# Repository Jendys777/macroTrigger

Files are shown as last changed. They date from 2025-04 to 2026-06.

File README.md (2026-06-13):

This is opensource project of a macro keyboard or pad. I call it macroTrigger. As it triggers some macros on your computer.

If you have any questions please read the manual first. Than send me a messagge with question. if you have one.

You can also find the 3D models here: https://www.printables.com/model/1269446-macrotrigger

UPDATE NOTES: 
- V3 firmware helps with the flashing process. Previously, you had to manually reset the device by shorting the RST and GND pins. Now, simply unplug the device, press and hold the encoder, and plug it back in. Keep holding the encoder while starting the flash in your IDE. Once the upload is finished, release the encoder, replug the device, and you are ready to go.

Please DO NOT SHARE, OR SELL THIS PRODCT, without my perrmision. 

contact me on: info@bojler.org

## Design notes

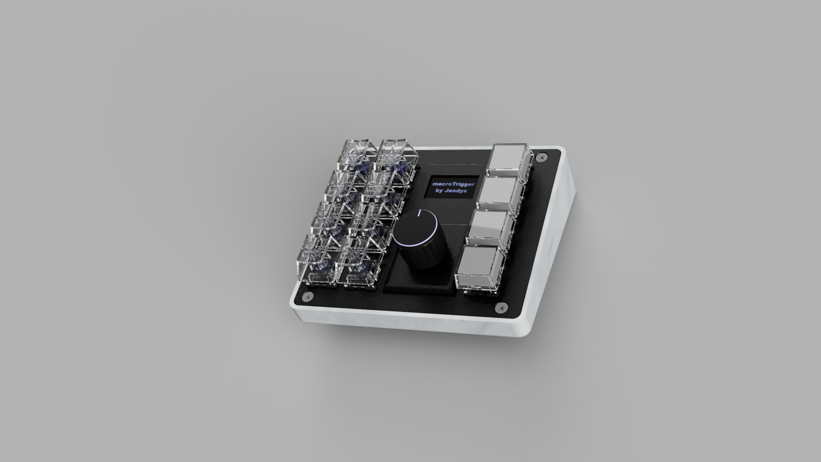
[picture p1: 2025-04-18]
Render1.PNG

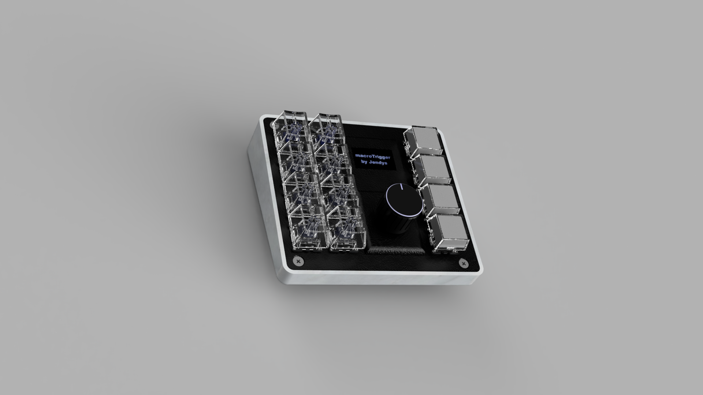
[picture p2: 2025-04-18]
Render2.PNG

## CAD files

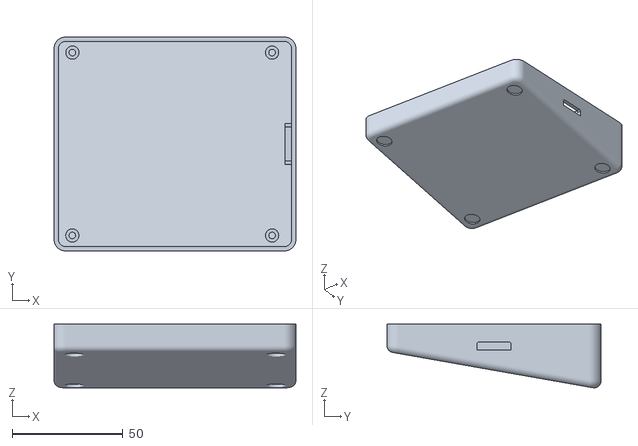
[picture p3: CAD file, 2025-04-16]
3DMODELS/macroTriggerBOTTOMCOVER.stl
109.2 x 96.6 x 28.8

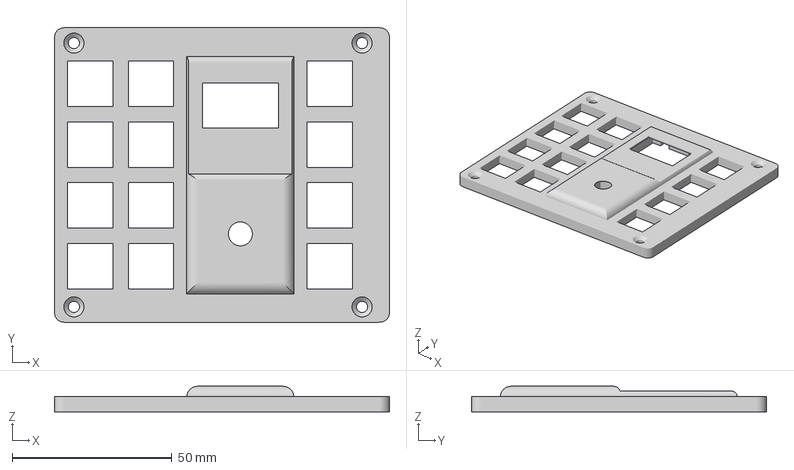
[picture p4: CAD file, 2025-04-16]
3DMODELS/macroTriggerTOPCOVER.3mf
104.8 x 92.2 x 8.00 mm

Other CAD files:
3DMODELS/macroTriggerTOPCOVER.stl

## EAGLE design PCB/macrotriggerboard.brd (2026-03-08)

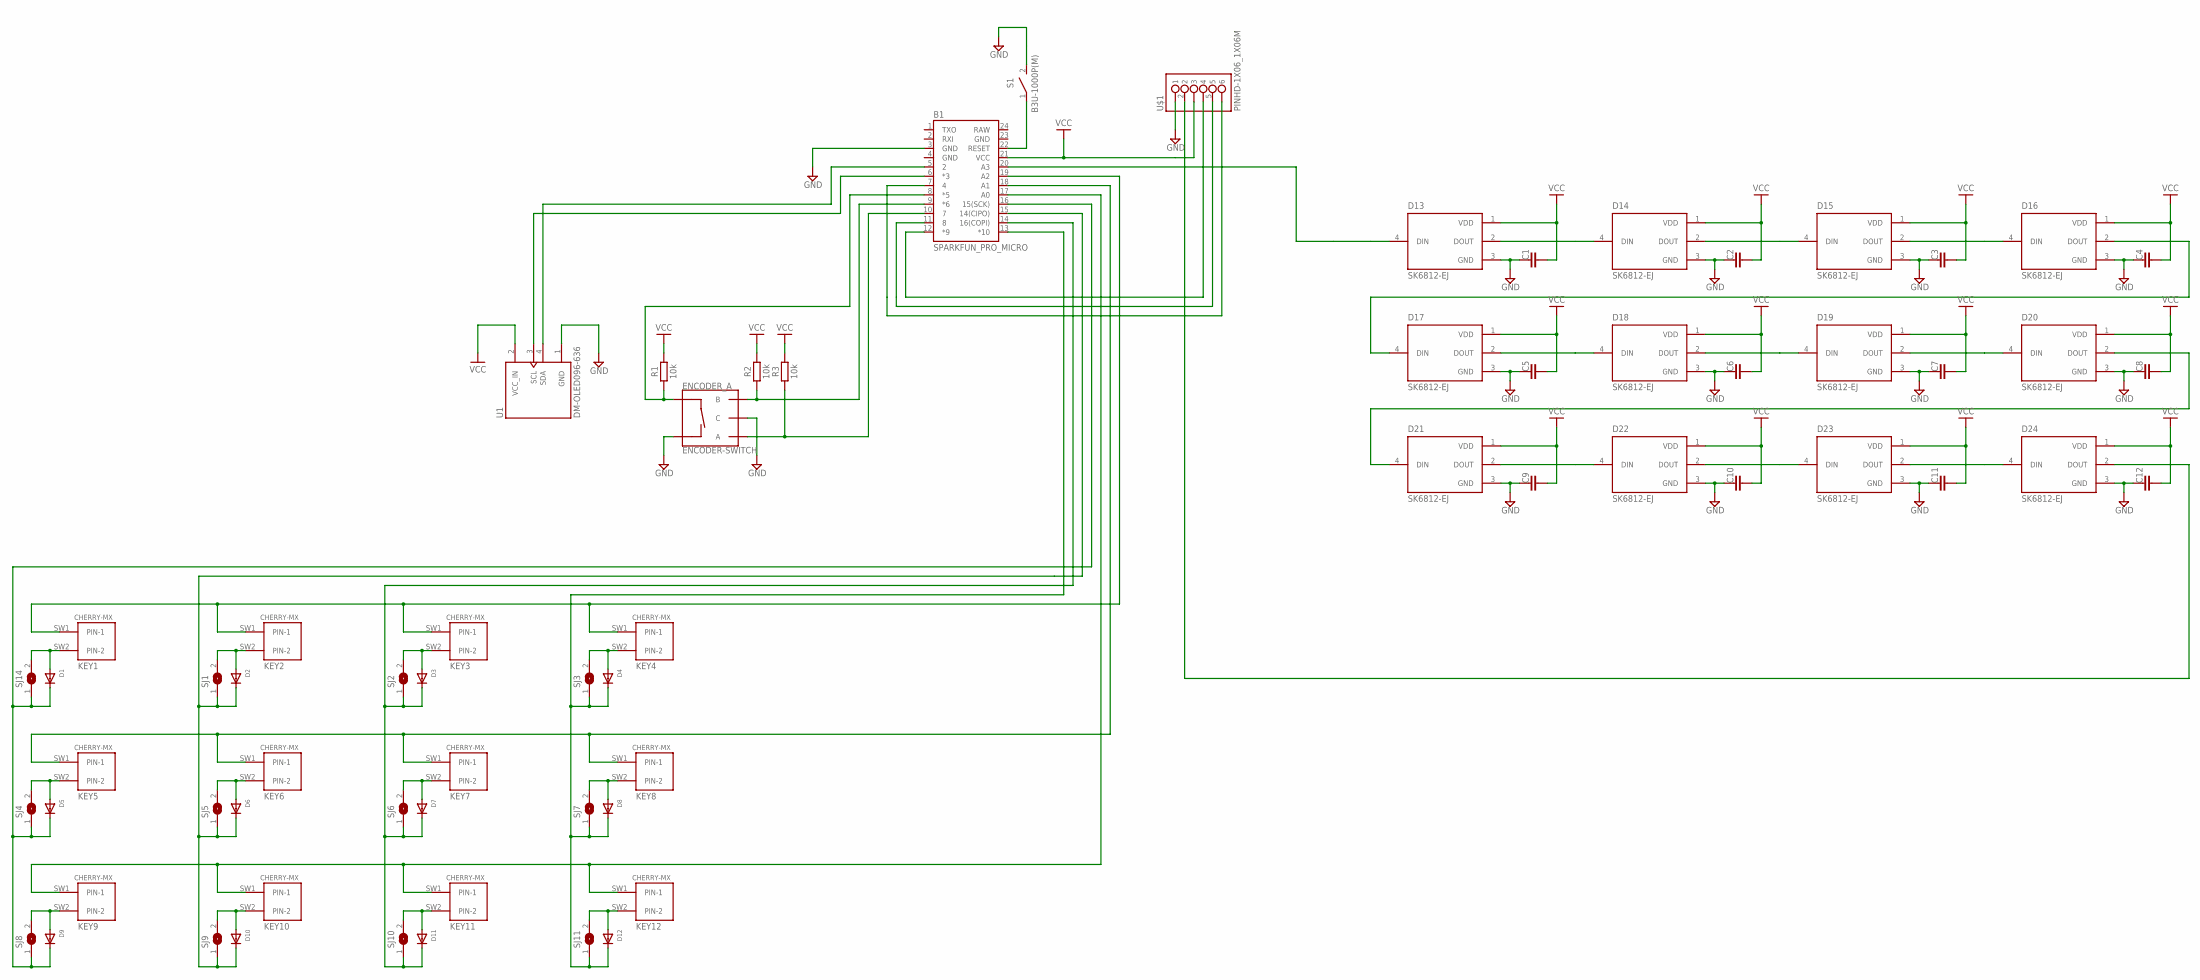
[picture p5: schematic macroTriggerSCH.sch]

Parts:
B1: SPARKFUN_PRO_MICRO
C1, C2, C3, C4, C5, C6, C7, C8, C9, C10, C11, C12: C_CHIP-0805(2012-METRIC); CAPC2012X110
D1, D2, D3, D4, D5, D6, D7, D8, D9, D10, D11, D12: DIODESOD-123; SOD-123
D13, D14, D15, D16, D17, D18, D19, D20, D21, D22, D23, D24: SK6812-EJ; LED_SK6812-E
ENCODER_A: ENCODER-SWITCH; ROTARY_ENC_PLAIN
KEY1, KEY2, KEY3, KEY4, KEY5, KEY6, KEY7, KEY8, KEY9, KEY10, KEY11, KEY12: CHERRY-MX
R1, R2, R3: 10k; RESC3216X70
S1: B3U-1000P(M)
SJ1, SJ2, SJ3, SJ4, SJ5, SJ6, SJ7, SJ8, SJ9, SJ10, SJ11, SJ14: SJ
U1: DM-OLED096-636; MODULE_DM-OLED096-636
U$1: PINHD-1X06_1X06M; 1X06

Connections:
GND: B1.3 (GND), B1.4 (GND), B1.23 (GND), C1.1, C2.1, C3.1, C4.1, C5.1, C6.1, C7.1, C8.1, C9.1, C10.1, C11.1, C12.1, D13.3 (GND), D14.3 (GND), D15.3 (GND), D16.3 (GND), D17.3 (GND), D18.3 (GND), D19.3 (GND), D20.3 (GND), D21.3 (GND), D22.3 (GND), D23.3 (GND), D24.3 (GND), ENCODER_A.C, ENCODER_A.SW-, S1.2, U1.1 (GND), U$1.1
unnamed: B1.22 (RESET), S1.1
unnamed: D1.A, KEY1.SW2 (PIN-2), SJ14.2
unnamed: D2.A, KEY2.SW2 (PIN-2), SJ1.2
unnamed: B1.15 (14(CIPO)), D2.C, D6.C, D10.C, SJ1.1, SJ5.1, SJ9.1
unnamed: D24.2 (DOUT), U$1.2
unnamed: B1.10 (7), ENCODER_A.A, R3.1
unnamed: D3.A, KEY3.SW2 (PIN-2), SJ2.2
unnamed: B1.19 (A2), KEY1.SW1 (PIN-1), KEY2.SW1 (PIN-1), KEY3.SW1 (PIN-1), KEY4.SW1 (PIN-1)
unnamed: D13.2 (DOUT), D14.4 (DIN)
unnamed: D4.A, KEY4.SW2 (PIN-2), SJ3.2
unnamed: B1.20 (A3), D13.4 (DIN)
unnamed: D5.A, KEY5.SW2 (PIN-2), SJ4.2
unnamed: D6.A, KEY6.SW2 (PIN-2), SJ5.2
unnamed: B1.13 (*10), D4.C, D8.C, D12.C, SJ3.1, SJ7.1, SJ11.1
unnamed: D7.A, KEY7.SW2 (PIN-2), SJ6.2
unnamed: D8.A, KEY8.SW2 (PIN-2), SJ7.2
unnamed: D9.A, KEY9.SW2 (PIN-2), SJ8.2
unnamed: D10.A, KEY10.SW2 (PIN-2), SJ9.2
unnamed: B1.14 (16(COPI)), D3.C, D7.C, D11.C, SJ2.1, SJ6.1, SJ10.1
unnamed: D11.A, KEY11.SW2 (PIN-2), SJ10.2
unnamed: D12.A, KEY12.SW2 (PIN-2), SJ11.2
unnamed: B1.11 (8), U$1.5
unnamed: B1.12 (*9), U$1.4
unnamed: B1.7 (4), U$1.6
unnamed: D14.2 (DOUT), D15.4 (DIN)
unnamed: D15.2 (DOUT), D16.4 (DIN)
unnamed: B1.18 (A1), KEY5.SW1 (PIN-1), KEY6.SW1 (PIN-1), KEY7.SW1 (PIN-1), KEY8.SW1 (PIN-1)
unnamed: B1.9 (*6), ENCODER_A.B, R2.1
unnamed: B1.8 (*5), ENCODER_A.SW+, R1.1
unnamed: B1.5 (2), U1.4 (SDA)
unnamed: B1.6 (*3), U1.3 (SCL)
unnamed: B1.17 (A0), KEY9.SW1 (PIN-1), KEY10.SW1 (PIN-1), KEY11.SW1 (PIN-1), KEY12.SW1 (PIN-1)
unnamed: D16.2 (DOUT), D17.4 (DIN)
unnamed: B1.16 (15(SCK)), D1.C, D5.C, D9.C, SJ4.1, SJ8.1, SJ14.1
unnamed: D17.2 (DOUT), D18.4 (DIN)
unnamed: D18.2 (DOUT), D19.4 (DIN)
unnamed: D19.2 (DOUT), D20.4 (DIN)
unnamed: D20.2 (DOUT), D21.4 (DIN)
unnamed: D21.2 (DOUT), D22.4 (DIN)
unnamed: D22.2 (DOUT), D23.4 (DIN)
unnamed: D23.2 (DOUT), D24.4 (DIN)
RAW: B1.24 (RAW)
VCC: B1.21 (VCC), C1.2, C2.2, C3.2, C4.2, C5.2, C6.2, C7.2, C8.2, C9.2, C10.2, C11.2, C12.2, D13.1 (VDD), D14.1 (VDD), D15.1 (VDD), D16.1 (VDD), D17.1 (VDD), D18.1 (VDD), D19.1 (VDD), D20.1 (VDD), D21.1 (VDD), D22.1 (VDD), D23.1 (VDD), D24.1 (VDD), R1.2, R2.2, R3.2, U1.2 (VCC_IN), U$1.3


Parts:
B1: SPARKFUN_PRO_MICRO
C1, C2, C3, C4, C5, C6, C7, C8, C9, C10, C11, C12: C_CHIP-0805(2012-METRIC); CAPC2012X110
D1, D2, D3, D4, D5, D6, D7, D8, D9, D10, D11, D12: DIODESOD-123; SOD-123
D13, D14, D15, D16, D17, D18, D19, D20, D21, D22, D23, D24: SK6812-EJ; LED_SK6812-E
ENCODER_A: ENCODER-SWITCH; ROTARY_ENC_PLAIN
KEY1, KEY2, KEY3, KEY4, KEY5, KEY6, KEY7, KEY8, KEY9, KEY10, KEY11, KEY12: CHERRY-MX
R1, R2, R3: 10k; RESC3216X70
S1: B3U-1000P(M)
SJ1, SJ2, SJ3, SJ4, SJ5, SJ6, SJ7, SJ8, SJ9, SJ10, SJ11, SJ14: SJ
U1: DM-OLED096-636; MODULE_DM-OLED096-636
U$1: PINHD-1X06_1X06M; 1X06

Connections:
GND: B1.3 (GND), B1.4 (GND), B1.23 (GND), C1.1, C2.1, C3.1, C4.1, C5.1, C6.1, C7.1, C8.1, C9.1, C10.1, C11.1, C12.1, D13.3 (GND), D14.3 (GND), D15.3 (GND), D16.3 (GND), D17.3 (GND), D18.3 (GND), D19.3 (GND), D20.3 (GND), D21.3 (GND), D22.3 (GND), D23.3 (GND), D24.3 (GND), ENCODER_A.C, ENCODER_A.SW-, S1.2, U1.1 (GND), U$1.1
unnamed: B1.22 (RESET), S1.1
unnamed: D1.A, KEY1.SW2 (PIN-2), SJ14.2
unnamed: D2.A, KEY2.SW2 (PIN-2), SJ1.2
unnamed: B1.15 (14(CIPO)), D2.C, D6.C, D10.C, SJ1.1, SJ5.1, SJ9.1
unnamed: D24.2 (DOUT), U$1.2
unnamed: B1.10 (7), ENCODER_A.A, R3.1
unnamed: D3.A, KEY3.SW2 (PIN-2), SJ2.2
unnamed: B1.19 (A2), KEY1.SW1 (PIN-1), KEY2.SW1 (PIN-1), KEY3.SW1 (PIN-1), KEY4.SW1 (PIN-1)
unnamed: D13.2 (DOUT), D14.4 (DIN)
unnamed: D4.A, KEY4.SW2 (PIN-2), SJ3.2
unnamed: B1.20 (A3), D13.4 (DIN)
unnamed: D5.A, KEY5.SW2 (PIN-2), SJ4.2
unnamed: D6.A, KEY6.SW2 (PIN-2), SJ5.2
unnamed: B1.13 (*10), D4.C, D8.C, D12.C, SJ3.1, SJ7.1, SJ11.1
unnamed: D7.A, KEY7.SW2 (PIN-2), SJ6.2
unnamed: D8.A, KEY8.SW2 (PIN-2), SJ7.2
unnamed: D9.A, KEY9.SW2 (PIN-2), SJ8.2
unnamed: D10.A, KEY10.SW2 (PIN-2), SJ9.2
unnamed: B1.14 (16(COPI)), D3.C, D7.C, D11.C, SJ2.1, SJ6.1, SJ10.1
unnamed: D11.A, KEY11.SW2 (PIN-2), SJ10.2
unnamed: D12.A, KEY12.SW2 (PIN-2), SJ11.2
unnamed: B1.11 (8), U$1.5
unnamed: B1.12 (*9), U$1.4
unnamed: B1.7 (4), U$1.6
unnamed: D14.2 (DOUT), D15.4 (DIN)
unnamed: D15.2 (DOUT), D16.4 (DIN)
unnamed: B1.18 (A1), KEY5.SW1 (PIN-1), KEY6.SW1 (PIN-1), KEY7.SW1 (PIN-1), KEY8.SW1 (PIN-1)
unnamed: B1.9 (*6), ENCODER_A.B, R2.1
unnamed: B1.8 (*5), ENCODER_A.SW+, R1.1
unnamed: B1.5 (2), U1.4 (SDA)
unnamed: B1.6 (*3), U1.3 (SCL)
unnamed: B1.17 (A0), KEY9.SW1 (PIN-1), KEY10.SW1 (PIN-1), KEY11.SW1 (PIN-1), KEY12.SW1 (PIN-1)
unnamed: D16.2 (DOUT), D17.4 (DIN)
unnamed: B1.16 (15(SCK)), D1.C, D5.C, D9.C, SJ4.1, SJ8.1, SJ14.1
unnamed: D17.2 (DOUT), D18.4 (DIN)
unnamed: D18.2 (DOUT), D19.4 (DIN)
unnamed: D19.2 (DOUT), D20.4 (DIN)
unnamed: D20.2 (DOUT), D21.4 (DIN)
unnamed: D21.2 (DOUT), D22.4 (DIN)
unnamed: D22.2 (DOUT), D23.4 (DIN)
unnamed: D23.2 (DOUT), D24.4 (DIN)
RAW: B1.24 (RAW)
VCC: B1.21 (VCC), C1.2, C2.2, C3.2, C4.2, C5.2, C6.2, C7.2, C8.2, C9.2, C10.2, C11.2, C12.2, D13.1 (VDD), D14.1 (VDD), D15.1 (VDD), D16.1 (VDD), D17.1 (VDD), D18.1 (VDD), D19.1 (VDD), D20.1 (VDD), D21.1 (VDD), D22.1 (VDD), D23.1 (VDD), D24.1 (VDD), R1.2, R2.2, R3.2, U1.2 (VCC_IN), U$1.3

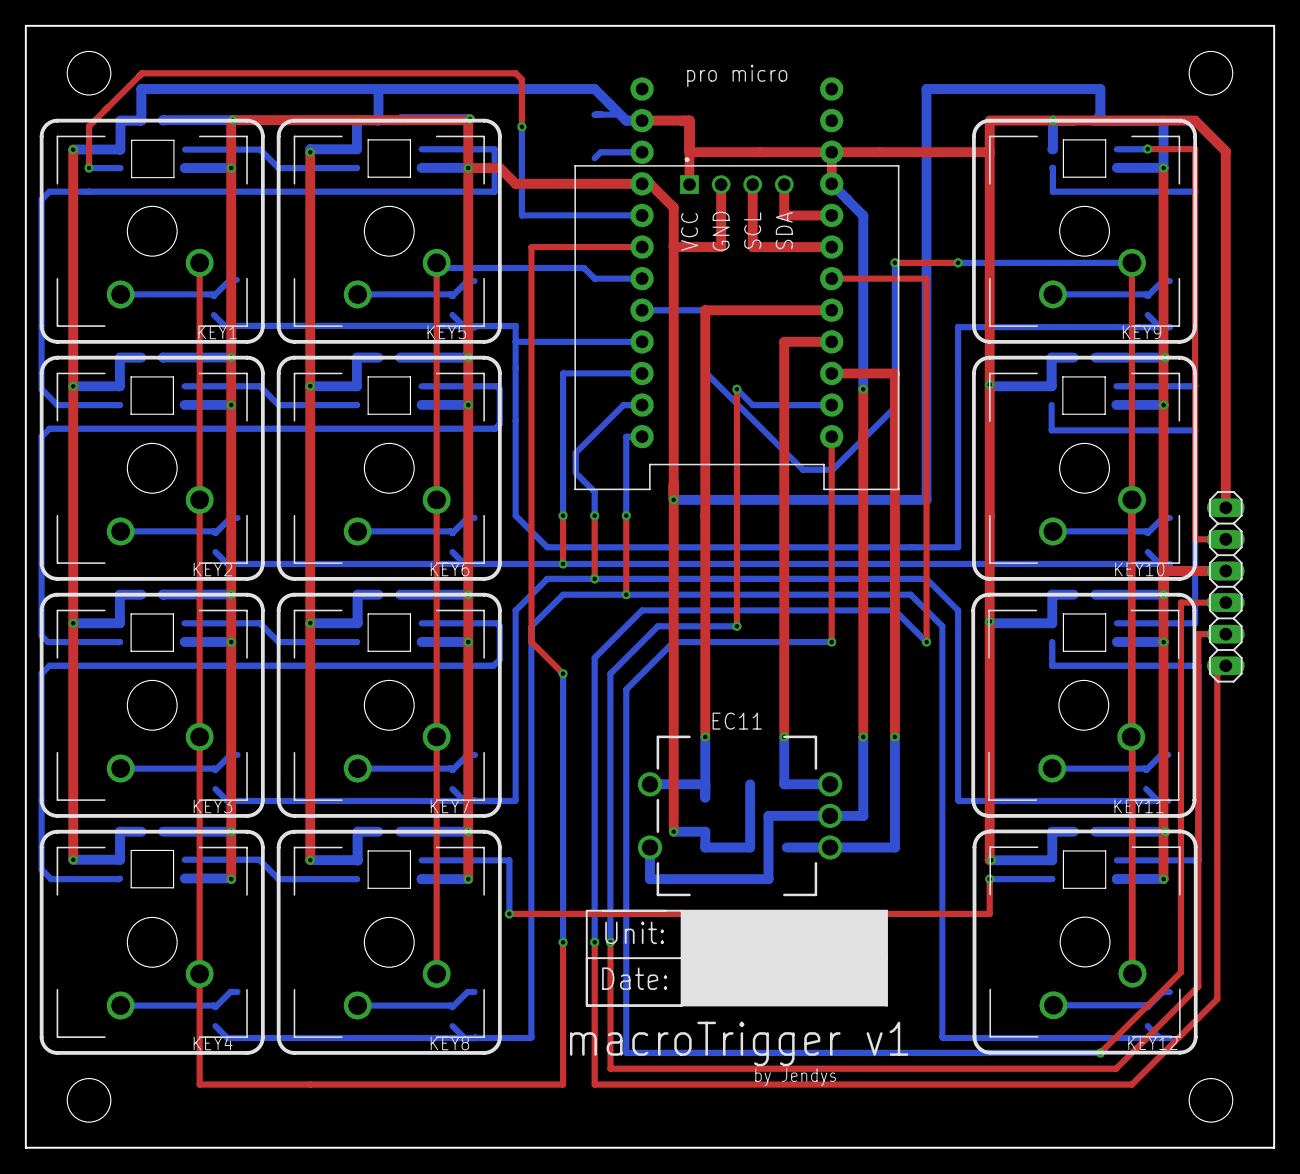
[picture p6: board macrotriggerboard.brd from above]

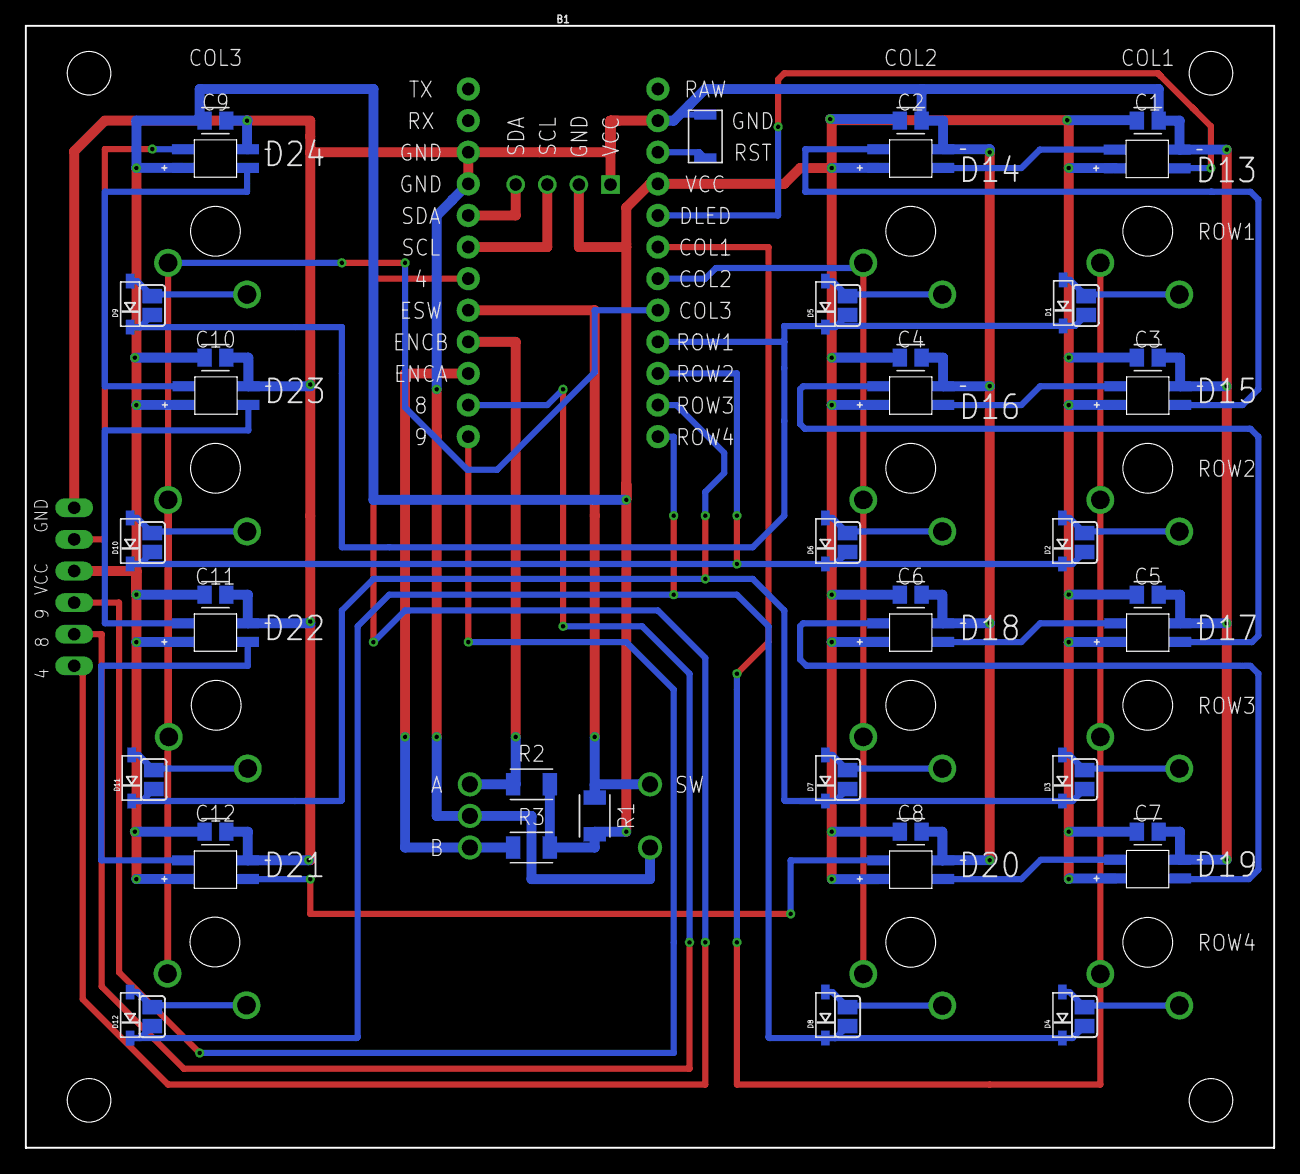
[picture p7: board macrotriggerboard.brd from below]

Board: 2 copper layers, 100.3 x 90.2 mm, 68 parts (53 on the bottom side), 43 nets.

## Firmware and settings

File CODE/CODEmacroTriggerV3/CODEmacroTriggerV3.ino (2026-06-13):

//Libraries
#include <Adafruit_NeoPixel.h>
#include <Keypad.h>
#include <Encoder.h>
#include <Wire.h>
#include <Adafruit_GFX.h>
#include <Adafruit_SSD1306.h>
#include <HID-Project.h>
#include <HID-Settings.h>
#include <EEPROM.h>

//NeoPixel Setup
#define LED_PIN A3
#define LED_COUNT 13 
Adafruit_NeoPixel strip(LED_COUNT, LED_PIN, NEO_GRB + NEO_KHZ800);

//OLED Display Setup
#define SCREEN_WIDTH 128
#define SCREEN_HEIGHT 64
#define OLED_RESET -1
Adafruit_SSD1306 display(SCREEN_WIDTH, SCREEN_HEIGHT, &Wire, OLED_RESET);

//Keypad Setup
const byte ROWS = 4;
const byte COLS = 3;
char hexaKeys[ROWS][COLS] = {
  { '1', '2', 'A' },
  { '3', '4', 'B' },
  { '5', '6', 'C' },
  { '7', '8', 'D' }
};
byte rowPins[ROWS] = { 15, 14, 16, 10 };
byte colPins[COLS] = { A2, A1, A0 };
Keypad customKeypad = Keypad(makeKeymap(hexaKeys), rowPins, colPins, ROWS, COLS);

//Encoder Setup
#define ENCODER_CLK 7
#define ENCODER_DT 6
#define ENCODER_SW 5
Encoder myEnc(ENCODER_CLK, ENCODER_DT);
long lastPosition = 0;
bool lastButtonState = HIGH;

//Timers
unsigned long lastKeyCheck = 0;
const unsigned long keyCheckInterval = 50;
unsigned long lastBPressTime = 0;
int bPressCount = 0;
const unsigned long doublePressInterval = 500;

// Button B Toggle Logic
bool bToggleState = false;  
const int BUTTON_B_LED = 10;

unsigned long lastMPressTime = 0;
int mPressCount = 0;

unsigned long lastLEDUpdateTime[3] = { 0, 0, 0 };
const unsigned long LEDUpdateInterval = 100;

//Saved variables
unsigned long mode = 1;
int ledA = 5;
int menu = 0;
int LED = 2;
bool mute = false;
bool enableL = false;
bool enable = true;
bool Light = true;
String function = "";
int bright = 100;

char preset1 = '1'; String pre1 = "Mode 1";
char preset2 = '2'; String pre2 = "Mode 2";
char preset3 = '3'; String pre3 = "Mode 3";
char preset4 = 'W'; String pre4 = "Windows M"; 

unsigned long currentMillis = millis();

void setup() {
  // --- NOUZOVÝ REŽIM PRO NAHRÁVÁNÍ KÓDU ---
  // Pokud držíš zmáčknuté tlačítko enkodéru při zapojení do USB,
  // macropad svítí oranžově a zastaví se, aby šlo normálně nahrávat.
  pinMode(ENCODER_SW, INPUT_PULLUP);
  if (digitalRead(ENCODER_SW) == LOW) {
    strip.begin();
    strip.setBrightness(50);
    for (int i = 0; i < LED_COUNT; i++) {
      strip.setPixelColor(i, strip.Color(255, 100, 0)); // Oranžová
    }
    strip.show();
    while (true) {
      // Nekonečná smyčka - procesor drží prázdnou USB linku připravenou pro flash.
    }
  }
  // --- KONEC NOUZOVÉHO REŽIMU ---

  Serial.begin(9600);
  strip.begin();
  EEPROM.get(10, bright);
  strip.setBrightness(bright);
  strip.show();
  display.begin(SSD1306_SWITCHCAPVCC, 0x3C);
  BootKeyboard.begin();
  Consumer.begin();

  //Startup animation Display
  display.clearDisplay();
  display.setTextColor(1);
  display.setTextSize(2);
  display.setCursor(35, 8);
  display.print("macro");
  display.setCursor(23, 28);
  display.print("Trigger");
  display.setTextSize(1);
  display.setCursor(16, 54);
  display.print("By: Jendys & KNC");
  display.display();

  //LEDs Startup
  for (int i = 0; i < LED_COUNT; i++) {
    strip.setPixelColor(i, strip.Color(255, 0, 0));
    strip.show();
    delay(100); 
  }
  EEPROM.get(0, mode);
  EEPROM.get(5, LED);
}

void loop() {
  currentMillis = millis();

  //Check keypad at interval
  if (currentMillis - lastKeyCheck >= keyCheckInterval) {
    lastKeyCheck = currentMillis;
    char key = customKeypad.getKey();
    if (key) {
      keyPress(key);
    }
  }

  // Handle Encoder Rotation
  long newPosition = myEnc.read() / 4;
  long encDiff = newPosition - lastPosition;

  switch (menu) {
    case 0: {
      // Volume Control
      if (encDiff > 0) Consumer.write(MEDIA_VOLUME_UP);
      else if (encDiff < 0) Consumer.write(MEDIA_VOLUME_DOWN);

      // Play / Pause
      bool buttonState = digitalRead(ENCODER_SW);
      if (buttonState == LOW && lastButtonState == HIGH) {
        Consumer.write(MEDIA_PLAY_PAUSE);
        delay(200);
      }
      lastButtonState = buttonState;

      enable = false;
      enableL = false;

      if (currentMillis - lastLEDUpdateTime[0] >= LEDUpdateInterval) {
        lastLEDUpdateTime[0] = currentMillis;
        setColor(LED);
        display.clearDisplay();
        display.setTextColor(1);
        display.setTextSize(1);
        display.setTextWrap(false);
        display.setCursor(6, 17);
        display.print(function);
        setDisplay(mode);
      }
      break;
    }
    case 1: {
      // Mode Selection
      if (encDiff > 0) mode = min(mode + 1, 4UL);
      else if (encDiff < 0) mode = max(mode - 1, 1UL);

      if (encDiff != 0) EEPROM.put(0, mode);

      enable = true;
      enableL = false;

      if (currentMillis - lastLEDUpdateTime[1] >= LEDUpdateInterval) {
        lastLEDUpdateTime[1] = currentMillis;
        setColor(LED);
        display.clearDisplay();
        display.setTextSize(1);
        display.setTextWrap(false);
        display.setCursor(33, 2);
        display.print("Select MODE");
        setDisplay(mode);
      }
      break;
    }
    case 2: {
      // Brightness Control
      if (encDiff > 0) bright = min(bright + 10, 250);
      else if (encDiff < 0) bright = max(bright - 10, 0);
      if (encDiff != 0) {
        strip.setBrightness(bright);
        EEPROM.put(10, bright);
      }

      enable = false;
      enableL = true;

      if (currentMillis - lastLEDUpdateTime[2] >= LEDUpdateInterval) {
        lastLEDUpdateTime[2] = currentMillis;
        setColor(LED);
        display.clearDisplay();
        display.setTextSize(1);
        display.setTextWrap(false);
        display.setCursor(33, 32);
        display.print("LED Editor");
        display.display();

        if (LED >= 9) LED = 2;
        else if (LED <= 1) LED = 8;
      }
      break;
    }
  }

  if (encDiff != 0) {
    lastPosition = newPosition;
  }
}

void setColor(int LED) {
  uint32_t c1 = strip.Color(255, 255, 255);
  uint32_t c2;
  switch (LED) {
    case 2: c2 = strip.Color(255, 255, 255); break;
    case 3: c2 = strip.Color(255, 0, 0); break;
    case 4: c2 = strip.Color(255, 255, 0); break;
    case 5: c2 = strip.Color(0, 255, 0); break;
    case 6: c2 = strip.Color(0, 255, 255); break;
    case 7: c2 = strip.Color(0, 0, 255); break;
    case 8: c2 = strip.Color(255, 0, 255); break;
    default: c2 = strip.Color(255, 255, 255); break;
  }

  for (int i = 0; i < LED_COUNT; i++) {
    strip.setPixelColor(i, c1);
    if (i >= 5) { 
      strip.setPixelColor(i - 5, c2);
    }
  }

  if (bToggleState) {
    strip.setPixelColor(BUTTON_B_LED, strip.Color(255, 0, 0));
  } else {
    strip.setPixelColor(BUTTON_B_LED, strip.Color(255, 255, 255));
  }

  strip.show();
}

void setDisplay(int mode) {
  if (enable == true) {
    display.setTextColor(1);
    display.setCursor(4, 20);
    if (mode == 1) display.print(pre1);
    else if (mode == 2) display.print(pre2);
    else if (mode == 3) display.print(pre3);
    else if (mode == 4) display.print(pre4);
  }

  display.setTextSize(mode == 1 ? 3 : 2);
  display.setCursor(mode == 1 ? 8 : 5, mode == 1 ? 41 : 48);
  display.println(preset1);
  
  display.setTextSize(mode == 2 ? 3 : 2);
  display.setCursor(mode == 2 ? 41 : (mode == 1 ? 47 : 38), mode == 2 ? 39 : 48);
  display.println(preset2);

  display.setTextSize(mode == 3 ? 3 : 2);
  display.setCursor(mode == 3 ? 73 : (mode == 4 ? 71 : 82), mode == 3 ? 39 : 48);
  display.println(preset3);

  display.setTextSize(mode == 4 ? 3 : 2);
  display.setCursor(mode == 4 ? 105 : 113, mode == 4 ? 39 : 48);
  display.println(preset4); 

  display.display();
  strip.show();
}

void handleControlKeys(char key) {
  switch (key) {
    case 'A': {
      unsigned long gg = millis();
      if (gg - lastMPressTime < doublePressInterval) mPressCount++;
      else mPressCount = 1;
      lastMPressTime = gg;
      if (mPressCount == 1 && menu == 0) {
        menu = 1;
        EEPROM.get(0, mode);
      } else if (mPressCount == 2 && menu == 1) {
        menu = 2;
        mPressCount = 0;
      } else if (menu >= 1) {
        menu = 0;
        EEPROM.get(0, mode);
      }
      break;
    }
    case 'B': {
      unsigned long now = millis();
      if (now - lastBPressTime < doublePressInterval) bPressCount++;
      else bPressCount = 1;
      lastBPressTime = now;
      if (bPressCount == 1) {
        BootKeyboard.press(KEY_F13);
        delay(10);
        BootKeyboard.release(KEY_F13);
        bToggleState = !bToggleState;
      } else if (bPressCount == 2) {
        BootKeyboard.press(KEY_F14);
        delay(10);
        BootKeyboard.release(KEY_F14);
        bPressCount = 0;
      }
      break;
    }
    case 'C': {
      if (enableL) {
        LED = LED + 1;
        EEPROM.put(5, LED);
      } else {
        Consumer.write(MEDIA_NEXT);
      }
      break;
    }
    case 'D': {
      if (enableL) {
        LED = LED - 1;
        EEPROM.put(5, LED);
      } else {
        Consumer.write(MEDIA_PREVIOUS);
      }
      break;
    }
  }
}

void keyPress(char key) {
  if (key == 'A' || key == 'B' || key == 'C' || key == 'D') {
    handleControlKeys(key);
    return;
  }

  int keyNum = key - '1';
  if (keyNum >= 0 && keyNum <= 7) {
    
    // 1. APPLY MODIFIERS BASED ON MODE
    if (mode == 2) {
      BootKeyboard.press(KEY_LEFT_CTRL);
    } else if (mode == 3) {
      BootKeyboard.press(KEY_LEFT_CTRL);
      BootKeyboard.press(KEY_LEFT_ALT);
    } else if (mode == 4) {
      switch (key) {
        case '1': // Ukaž Plochu (Win + D)
        case '3': // Historie schránky (Win + V)
        case '6': // Zámek PC (Win + L)
          BootKeyboard.press(KEY_LEFT_GUI);
          break;
        case '2': // Trvalé smazání (Shift + Delete)
          BootKeyboard.press(KEY_LEFT_SHIFT);
          break;
        case '4': // Správce úloh (Ctrl + Shift + Esc)
          BootKeyboard.press(KEY_LEFT_CTRL);
          BootKeyboard.press(KEY_LEFT_SHIFT);
          break;
        case '5': // Zavřít okno (Alt + F4)
          BootKeyboard.press(KEY_LEFT_ALT);
          break;
        case '7': // Přepnutí plochy vlevo (Ctrl + Win)
        case '8': // Přepnutí plochy vpravo (Ctrl + Win)
          BootKeyboard.press(KEY_LEFT_CTRL);
          BootKeyboard.press(KEY_LEFT_GUI);
          break;
      }
    }

    // 2. APPLY BASE KEYS
    KeyboardKeycode fKeys[] = {KEY_F15, KEY_F16, KEY_F17, KEY_F18, KEY_F19, KEY_F20, KEY_F21, KEY_F22};
    
    if (mode == 1 || mode == 2 || mode == 3) {
      BootKeyboard.press(fKeys[keyNum]);
      function = "Function " + String(key);
    } else if (mode == 4) {
      switch (key) {
        case '1': BootKeyboard.press(KEY_D); function = "Show Desktop"; break; // Win + D
        case '2': BootKeyboard.press(KEY_DELETE); function = "Hard Delete"; break; // Shift + Del
        case '3': BootKeyboard.press(KEY_V); function = "Clipboard"; break; // Win + V
        case '4': BootKeyboard.press(KEY_ESC); function = "Task Mgr"; break; // Ctrl + Shift + Esc
        case '5': BootKeyboard.press(KEY_F4); function = "Close Window"; break; // Alt + F4
        case '6': BootKeyboard.press(KEY_L); function = "Lock PC"; break; // Win + L
        case '7': BootKeyboard.press(KEY_LEFT_ARROW); function = "Desk Left"; break; // Ctrl + Win + vlevo
        case '8': BootKeyboard.press(KEY_RIGHT_ARROW); function = "Desk Right"; break; // Ctrl + Win + vpravo
      }
    }

    // 3. RELEASE
    delay(20); 
    BootKeyboard.releaseAll();
  }
}

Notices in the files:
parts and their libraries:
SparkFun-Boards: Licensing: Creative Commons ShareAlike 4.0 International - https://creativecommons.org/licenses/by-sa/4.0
